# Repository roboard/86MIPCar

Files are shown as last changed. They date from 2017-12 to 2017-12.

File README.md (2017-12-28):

# 86MIPCar

Mobile inverted pendulum with 86Duino.

This project is inspired by JJROBOTS' B-ROBOT, which is a self balanced Arduino robot with stepper motors.
One can refer to their project at http://jjrobots.com/b-robot

### Required hardware

1. 86Duino One (http://www.86duino.com/index.php?p=70)
2. Prototype shield for Arduino Uno 
3. A4988 Stepper motor driver carrier x2 (https://www.pololu.com/product/1182)
4. NEMA17 Stepper motor x2 (http://www.motechmotor.com/products_detail.php?id=147&cid=70&page=1)
5. 2 channels RC transmitter and receiver
6. 3D printer : 86Duino Enjoy (http://www.86duino.com/?page_id=11733)

### Build environment

86Duino IDE, coding 315 (http://www.86duino.com/?page_id=8918)

### Build procedure

1. Connect all wires by following the attached connection document.
2. Connect 86Duino One to your PC's usb port.
3. Open 86Duino IDE.
4. Open mip.ino from its corresponding folder.
5. Compile mip.ino and download the compiled binary file into the connected 86Duino One.

### Known issue

PID gains depend on the chosen stepper motors and other mechanical parts. They should be tuned carefully. 

### Demo Video
<div align=center>
<a href="https://www.youtube.com/watch?v=nLcuCH0ktfU">86MIPCar</a>
</div>

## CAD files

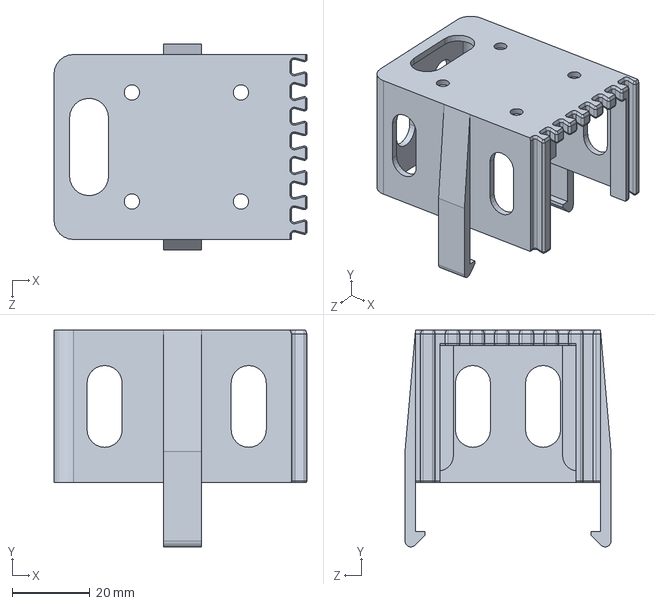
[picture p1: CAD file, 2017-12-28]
Mechanism/battery_cover.SLDPRT
65.0 x 55.7 x 52.9 mm

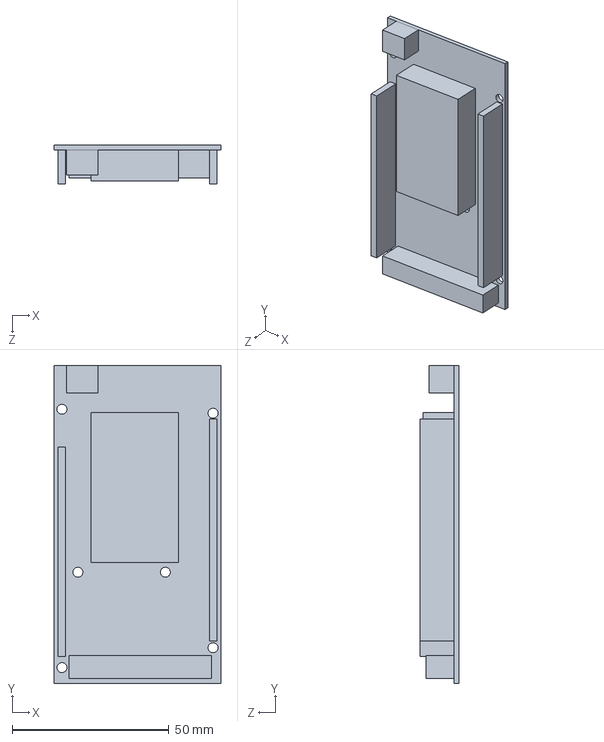
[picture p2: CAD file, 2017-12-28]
Mechanism/86duino.SLDPRT
53.3 x 101.6 x 12.6 mm

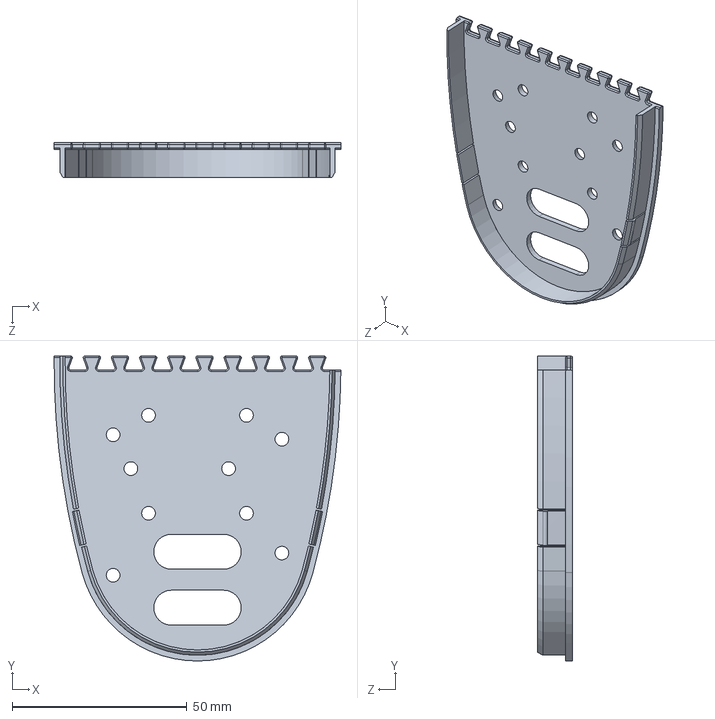
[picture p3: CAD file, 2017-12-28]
Mechanism/pcb_base.SLDPRT
82.0 x 87.2 x 10.0 mm

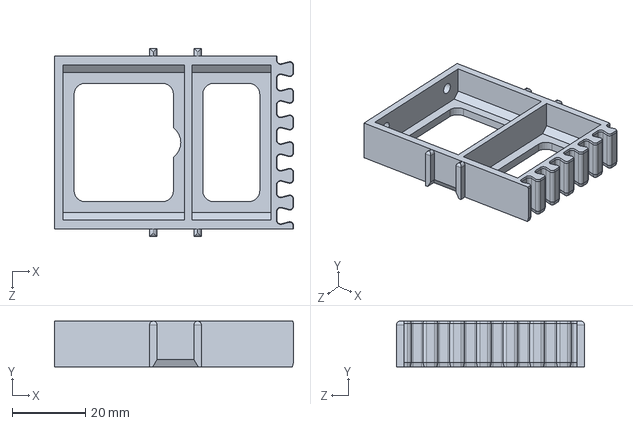
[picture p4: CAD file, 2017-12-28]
Mechanism/base.SLDPRT
65.2 x 12.5 x 51.3 mm

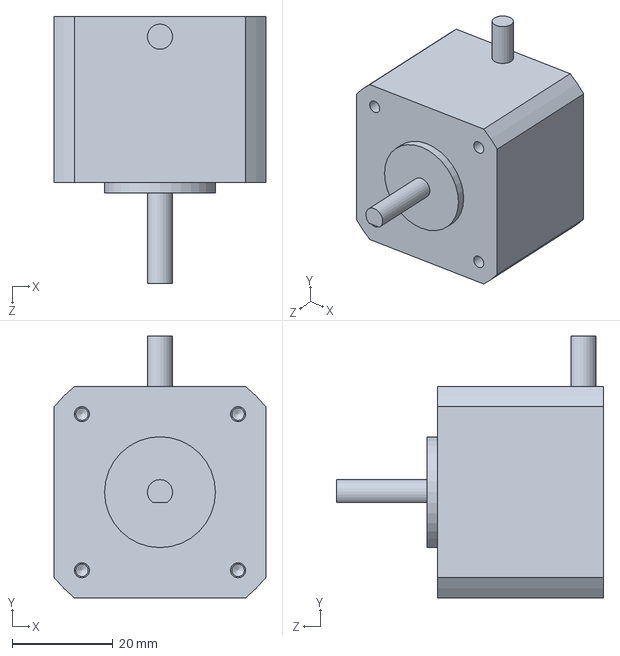
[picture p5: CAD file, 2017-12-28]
Mechanism/motor.SLDPRT
42.0 x 52.0 x 53.0 mm

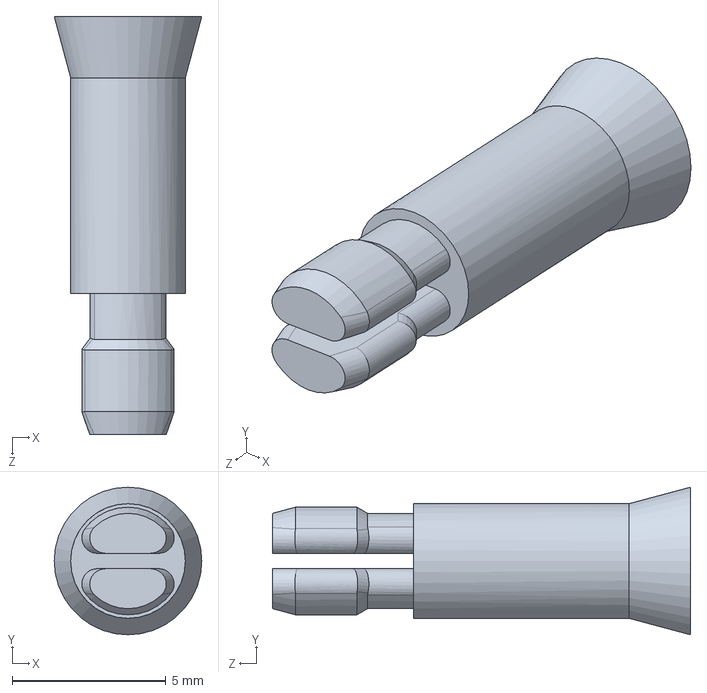
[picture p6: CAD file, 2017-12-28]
Mechanism/pin1.SLDPRT
4.80 x 4.80 x 13.6 mm

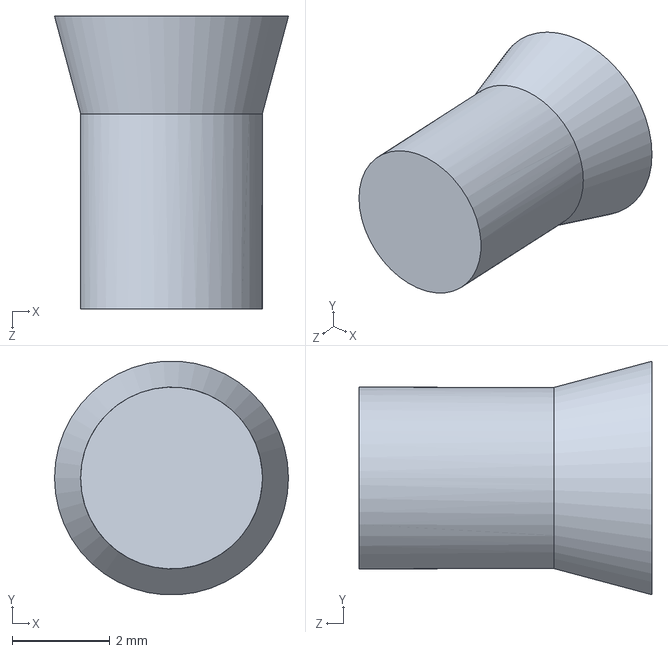
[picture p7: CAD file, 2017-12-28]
Mechanism/pin2.SLDPRT
4.80 x 4.79 x 6.00 mm

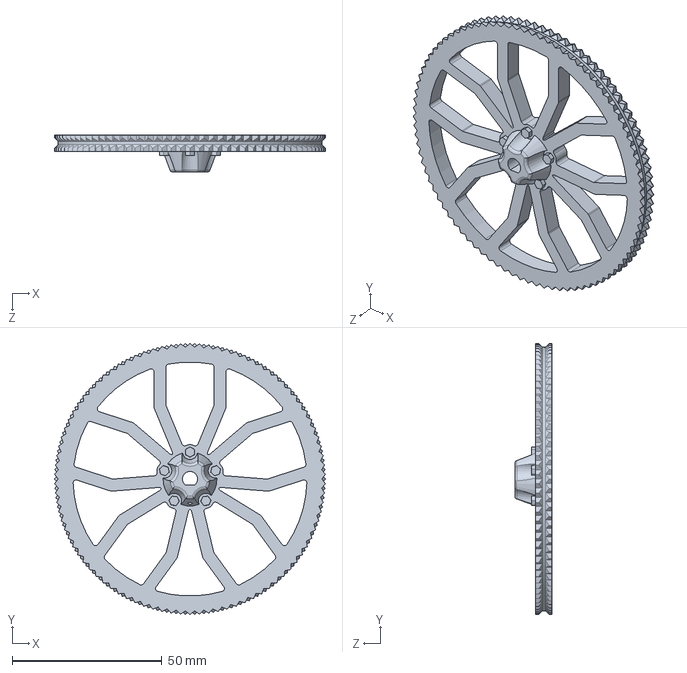
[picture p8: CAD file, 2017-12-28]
Mechanism/wheel.SLDPRT
90.4 x 90.4 x 12.5 mm

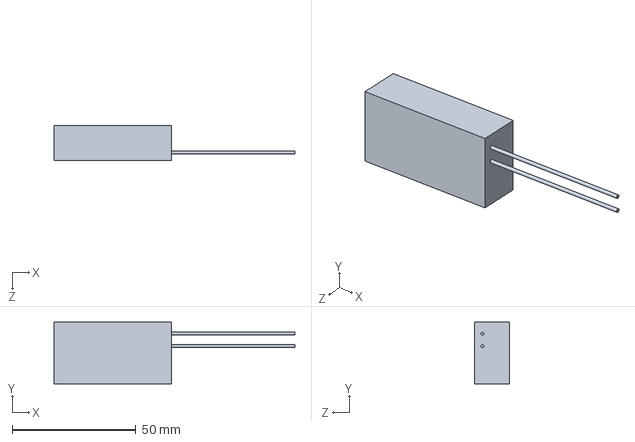
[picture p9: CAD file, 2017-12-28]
Mechanism/Receiver.SLDPRT
97.5 x 25.0 x 14.3 mm

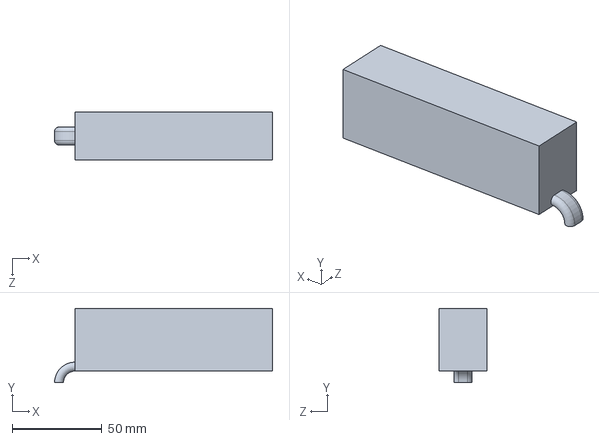
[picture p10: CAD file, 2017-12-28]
Mechanism/battery.SLDPRT
121.5 x 41.5 x 27.0 mm

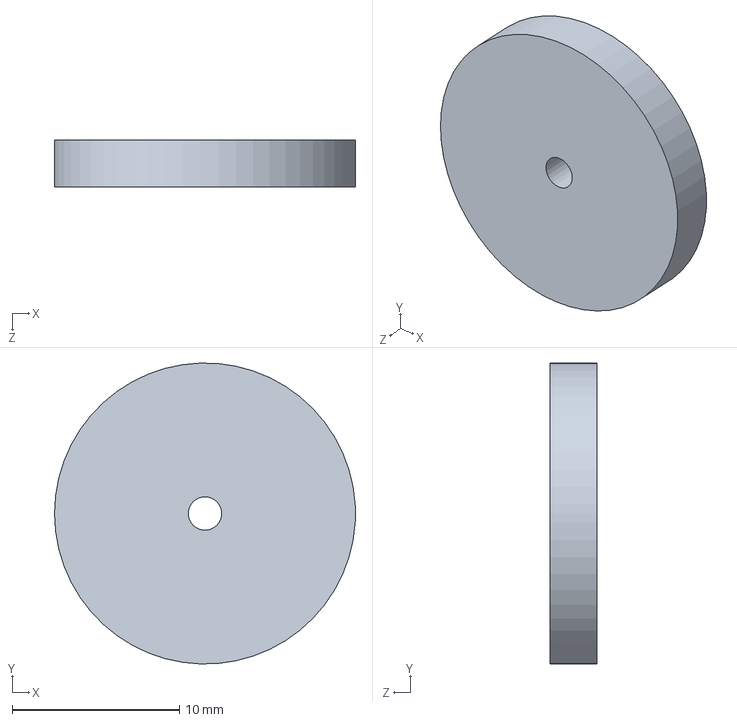
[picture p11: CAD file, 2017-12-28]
Mechanism/wheel3.SLDPRT
18.0 x 18.0 x 2.80 mm

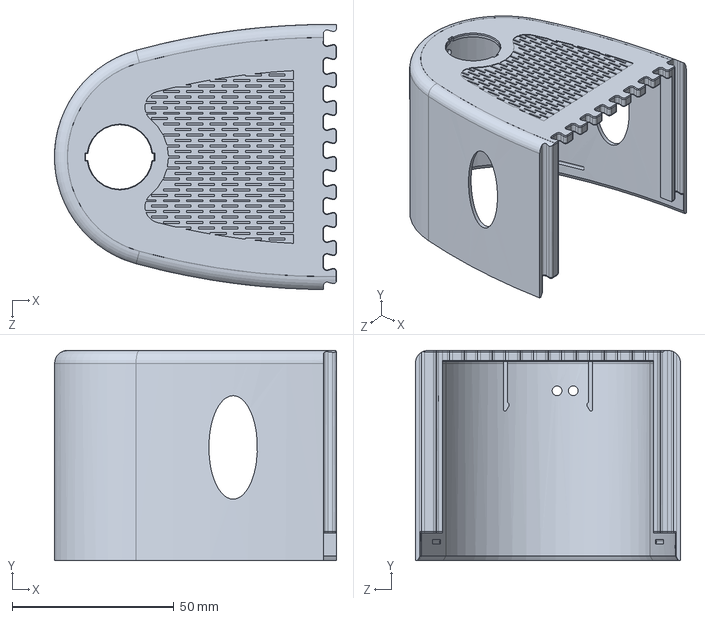
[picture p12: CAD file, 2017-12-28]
Mechanism/pcb_cover.SLDPRT
87.2 x 65.0 x 82.0 mm

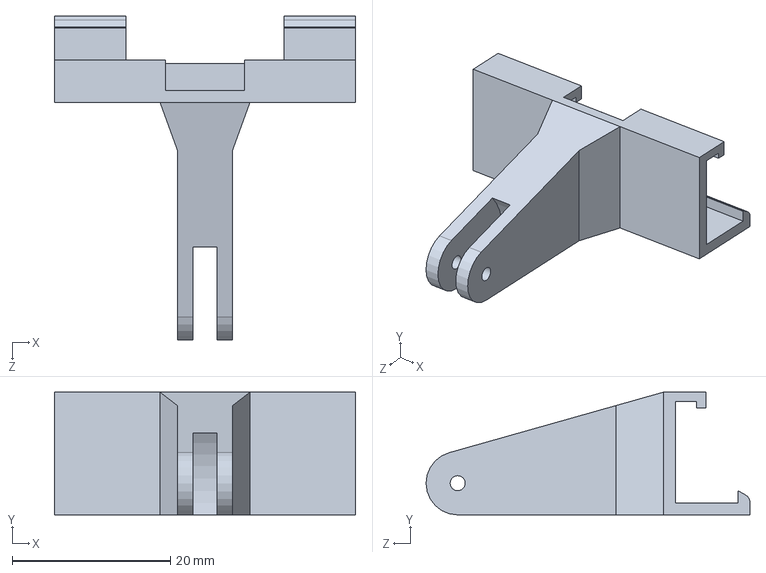
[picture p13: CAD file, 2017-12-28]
Mechanism/stabilizers.SLDPRT
38.0 x 15.5 x 40.9 mm

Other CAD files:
Mechanism/STL/base.STL
Mechanism/STL/battery_cover.STL
Mechanism/STL/pcb_base.STL
Mechanism/STL/pin1.STL
Mechanism/STL/pin2.STL
Mechanism/STL/stabilizers.STL
Mechanism/STL/wheel3.STL

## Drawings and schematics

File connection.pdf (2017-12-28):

# Connection for stepper motor driver carrier 1

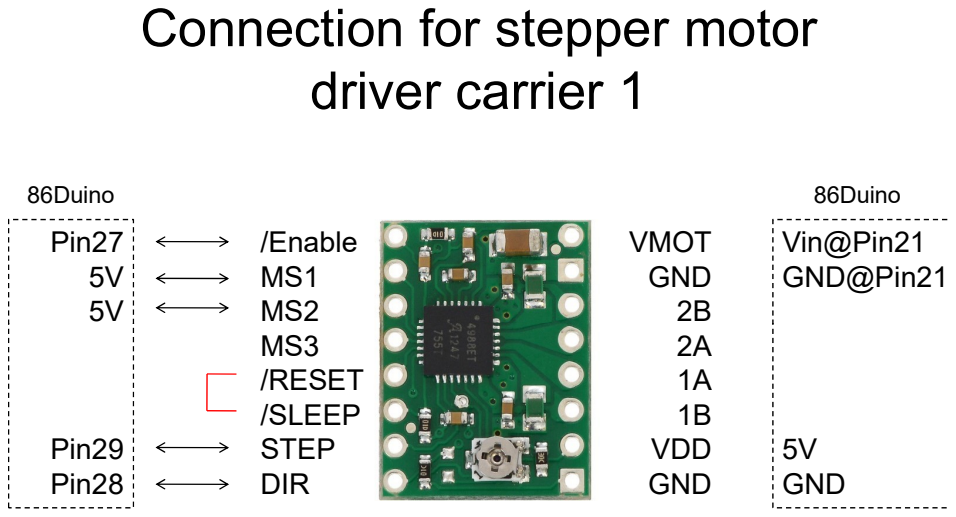
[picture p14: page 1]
/Enable MS1 MS2; VMOT GND 2B; Pin27 5V 5V; Vin@Pin21 GND@Pin21; 86Duino; MS3 /RESET /SLEEP STEP DIR; 2A 1A 1B VDD GND; Pin29 Pin28; 5V GND

# Connection for stepper motor driver carrier 2

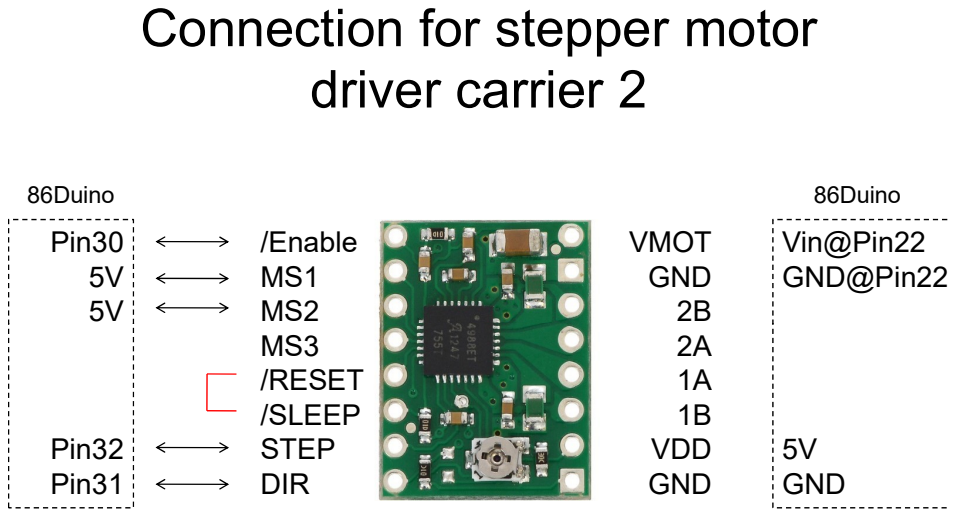
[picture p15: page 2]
/Enable MS1 MS2; VMOT GND 2B; Pin30 5V 5V; Vin@Pin22 GND@Pin22; 86Duino; MS3 /RESET /SLEEP STEP DIR; 2A 1A 1B VDD GND; Pin32 Pin31; 5V GND

# Connection for RC receiver

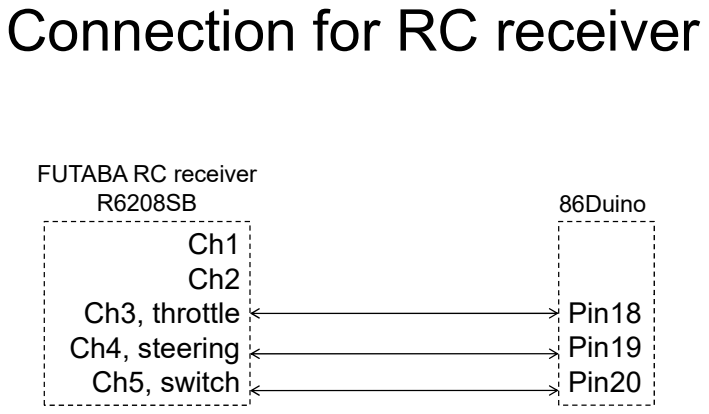
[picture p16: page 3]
FUTABA RC receiver; 86Duino; Ch3, throttle Ch4, steering Ch5, switch; Pin18 Pin19 Pin20

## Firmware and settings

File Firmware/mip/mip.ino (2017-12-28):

/*  Mobile Inverted Pendulum Robot
 *  
 *  This project is inspired by JJROBOTS' B-ROBOT, which is a self balanced Arduino robot with stepper motors.
 *  One can refer to their project at http://jjrobots.com/b-robot 
 *  
 *  Author: Bang-Yu Liu
 *  Date: 31/10/2017
 *  Version: 0.1
 *  License: GPL v2
 *
 *  The MIP robot can raise up itself with the help of two arms, front and back. Throttle and direction commands are
 *  given via an RC transmitter and receiver. The width of PWM signals from the receiver is determined by the capture function of encoder
 *  modules. Then the signals are converted into throttle and direction commands, respectively.
 *  The MIP robot is controlled with a cascade control scheme. The outer loop takes the throttle command as its input
 *  then calculates a demanding tilting angle and feeds the angle command into the inner loop. 
 *  The inner loop stablizes the tilting angle of the robot by adjusting the rotational speed of two stepper motors.
 *  The tilting angle is obtained from the built-in IMU on a 86Duino One. One can access the angle information with 
 *  the FreeIMU1 library.
 */

#include <EEPROM.h>
#include <Encoder.h>
#include <Wire.h>
#include "FreeIMU1.h"
#include "TimerOne.h"
 
/* stepper section
*
*/
// define pins numbers
const int enPin_1 = 27; 
const int dirPin_1 = 28;
const int stepPin_1 = 29;
const int enPin_2 = 30;
const int dirPin_2 = 31;
const int stepPin_2 = 32;
// define variables
int dir = 0;  
int timerPeriod;
int speedM = 0;
int disabler = 1100;

/* stability controller
*
*/
const int MAX_ACCEL = 200;
float kpStab = 8.0;
float kdStab = 5000.0;
long timeOld;
long timeValue;
float dt;
float ypr[3];
float angle = 0.0;
float angleOld = 0.0;
float angleF = 0.0;
float tangle = 0.0;
float tangleOld = 0.0;
float setPointOld = 0.0;
float PIDErrorOld = 0.0;
float PIDErrorOld2 = 0.0;
float ctrlOutput = 0.0;

/* speed controller
*
*/
const int ITERM_MAX_ERROR = 80;
const int ITERM_MAX = 8000;
float kpSpd = 0.04;
float kiSpd = 0.08;
float targetSpd = 0.0;
float targetSpdOld = 0.0;
float fbkSpd = 0.0;
float estSpd = 0.0;
float PIDSpdErrorSum = 0.0;
float errorOld = 0.0;

/* throttle and steering input command
*
*/
const int UPPER_BOUND = 1700;
const int LOWER_BOUND = 1300;
int direction = 0; // 0: straight, -1: left, 1: right.
int steering = 1500;
int throttle = 1100;

void setMotorSpeed(int tspeed)
{ 
 
	int speed;
		
	speedM = tspeed;
	speed = speedM * 13; // rpm * (1600/60) = rpm * 26, 26/2 = 13 due to 2 pulses in one interrupt 

	if (speed==0) {
		dir = 0;
	}
	else if (speed>0)
	{
		timerPeriod = 1000000 / speed;   
		dir = 1;
		digitalWrite(dirPin_1, LOW); // Enables the motor to move in a particular direction
		digitalWrite(dirPin_2, HIGH);
	}
	else
	{
		timerPeriod = 1000000 / (-speed);
		dir = -1;
		digitalWrite(dirPin_1, HIGH); // Enables the motor to move in a particular direction
		digitalWrite(dirPin_2, LOW);
	}
	Timer1.setPeriod(timerPeriod);
}

void ISR_motor()
{
	if (dir == 0) return;
	
	if (direction <= 0) {
		digitalWrite(stepPin_1,HIGH);
	}
	if (direction >= 0) {
		digitalWrite(stepPin_2,HIGH);
	}
	delayMicroseconds(2);
	if (direction <= 0) {
		digitalWrite(stepPin_1,LOW);
	}
	if (direction >= 0) {
		digitalWrite(stepPin_2,LOW);
	}
	
	digitalWrite(stepPin_1,HIGH);
	digitalWrite(stepPin_2,HIGH);
	delayMicroseconds(2); 
	digitalWrite(stepPin_1,LOW);
	digitalWrite(stepPin_2,LOW);
}

// PD controller implementation(Proportional, derivative). DT is in miliseconds
float stabilityPDControl(float DT, float input, float setPoint, float Kp, float Kd)
{
  float error;
  float output;

  error = setPoint - input;

  // Kd is implemented in two parts
  //    The biggest one using only the input (sensor) part not the SetPoint input-input(t-2)
  //    And the second using the setpoint to make it a bit more agressive   setPoint-setPoint(t-1)
  output = Kp * error + (Kd * (setPoint - setPointOld) - Kd * (input - PIDErrorOld)) / DT;
  
  PIDErrorOld2 = PIDErrorOld;
  PIDErrorOld = input;  // error for Kd is only the input component
  setPointOld = setPoint;
  return (output);
}

float speedPIControl(float DT, float input, float setPoint, float Kp, float Ki)
{
  float error;
  float output;

  error = setPoint - input;
  PIDSpdErrorSum += constrain(error, -ITERM_MAX_ERROR, ITERM_MAX_ERROR);
  PIDSpdErrorSum = constrain(PIDSpdErrorSum, -ITERM_MAX, ITERM_MAX);

  output = Kp * error + Ki * PIDSpdErrorSum * DT * 0.001; // DT is in miliseconds
  errorOld = error;
  return (output);
}

// Set the FreeIMU object
FreeIMU1 my3IMU = FreeIMU1();

void setup() {
	Serial.begin(9600);
	
	// Initialize encoder 1 in capture mode
	Enc1.begin(MODE_CAPTURE);
	
	// Initialize the onboard IMU
	Wire.begin();
  
	delay(5);
	my3IMU.init(1); // the parameter enable or disable fast mode
	delay(5);
	
	// Sets the six pins as Outputs
	pinMode(enPin_1, OUTPUT); 
	pinMode(dirPin_1, OUTPUT);
	pinMode(stepPin_1, OUTPUT);  
	digitalWrite(enPin_1, HIGH); // Diarm the coils of the first stepper

	pinMode(enPin_2, OUTPUT); 
	pinMode(dirPin_2, OUTPUT);
	pinMode(stepPin_2, OUTPUT);  
	digitalWrite(enPin_2, HIGH); // Diarm the coils of the second stepper
	
	// Initialize timer1 and attach an ISR to it
	Timer1.initialize(500000);         // initialize timer1, and set a 1/2 second period by default
	Timer1.attachInterrupt(ISR_motor);  // attaches ISR_motor() as a timer overflow interrupt
	
	// get current time with millis()
	timeOld = millis();
}

void loop() {
	
	// System on/off
	disabler = Enc1.pulseIn(2, HIGH); // pin 20 of 86duino One
	
	if (disabler > 1300) {
		digitalWrite(enPin_1, LOW); // Arm the coils of the first stepper
		digitalWrite(enPin_2, LOW); // Arm the coils of the second stepper
	}
	else {
		digitalWrite(enPin_1, HIGH); // Disarm the coils of the first stepper
		digitalWrite(enPin_2, HIGH); // Disarm the coils of the second stepper
		PIDSpdErrorSum = 0.0; // reset I speed controller
	}
	
	// Steering cmd
	steering = Enc1.pulseIn(1, HIGH); // pin 19 of 86duino One
	
	if (steering > UPPER_BOUND) {
		direction = 1; // turn right
	}
	else if (steering < LOWER_BOUND) {
		direction = -1; // turn left
	}
	else {
		direction = 0; // go straight
	}
	
	
	// Throttle cmd
	throttle = Enc1.pulseIn(0, HIGH); // pin 18 of 86duino One
		
	if (1400 < throttle && throttle < 1600) {
		throttle = 1500;
	}
	else {
		throttle = throttle;
	}
	
	if (1400 < throttle && throttle < 1600) {
		targetSpd = 0.0;
	}
	else if (throttle <= 1400) {
		targetSpd = (float)((throttle - 1400) / 2);
	}
	else {
		targetSpd = (float)((throttle - 1600) / 2);
	}
	targetSpdOld = 0.2 * targetSpd + 0.8 * targetSpdOld;
	targetSpdOld = constrain(targetSpdOld, -100.0, 100.0);
	
	// Update time
	timeValue = millis();
	dt = (float)(timeValue - timeOld);
	timeOld = timeValue;
	
	// Tilting angle raw and filtered inputs
	my3IMU.getYawPitchRoll(ypr);
	angle = ypr[1];
	angleF = 0.025 * angle + 0.975 * angleF;
	angleOld = angleF;
	
	// Speed raw and filtered inputs
	fbkSpd = -1.2 * ctrlOutput;
	estSpd = 0.1 * fbkSpd + 0.9 * estSpd;
	
	// Outter loop controller for the speed
	tangle = speedPIControl(dt, estSpd, targetSpdOld, kpSpd, kiSpd);
	tangleOld = 0.1 * tangle + 0.9 * tangleOld;
	tangleOld = constrain(tangleOld, -30.0, 30.0);
	
	// Inner loop controller for the stability of the tilting
	ctrlOutput = stabilityPDControl(dt, angleF, tangleOld, kpStab, kdStab);
	ctrlOutput = constrain(ctrlOutput, -300.0, 300.0);
	
	// Control output
	setMotorSpeed((int)ctrlOutput);
}
